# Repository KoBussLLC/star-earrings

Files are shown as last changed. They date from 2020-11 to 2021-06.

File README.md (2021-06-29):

# star-earrings

PCB earrings to show the world that you are there!

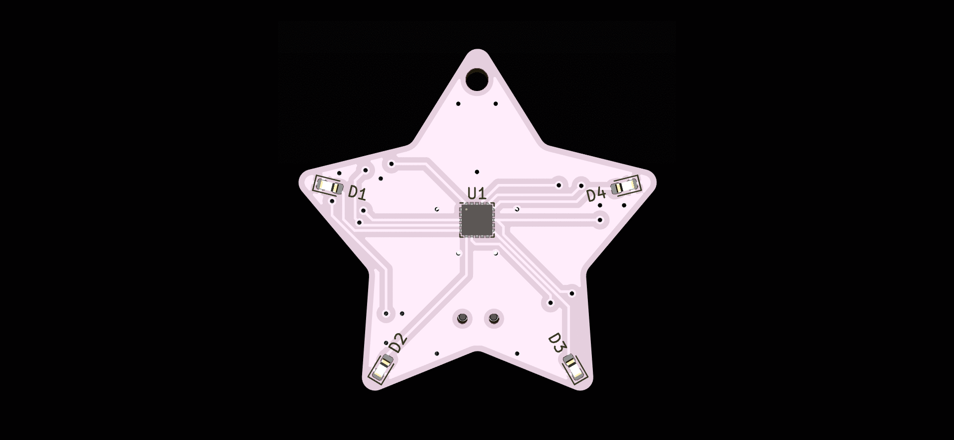
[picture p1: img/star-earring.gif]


## Features

- 4 bright white LEDs
- Mode changing push button
- On/Off Switch
- CR1220 battery life estimated at 570 hours (40mAh/0.07mA)
- Open-source hardware and software allow customizable LED patterns

## Design Considerations

- As light weight as possible -> 0.8mm PCB Thickness
- Balance battery weight/life -> CR1220 Button Cell Battery
- Bright LEDs -> PWM controlled to avoid inline resistor
- Minimal aesthetic -> UFQFPN20 microcontroller footprint
- Power Saving -> STM32L011U6
- No loss of battery while in storage -> Slide switch for on/off
- Mode changing -> Push Button to switch LED patterns
- SMD Manufacturing/Assembly -> 100% SMD Components with dual side panelized assembly

## Firmware

The firmware for the earrings uses the open-source [libopencm3](http://libopencm3.org/) library

- TIM2 used for PWM
- TIM21 used for LED pattern changing interrupt
- EXTI4 Interrupt used for push button
- LPTIM1 used for button debounce

### Generate PWM Sine Waves

Short python3 script to generate breathing pattern array. Modify this script and TIM2 values to customize LED patterns

``` python
import numpy as np
import math

t = np.linspace(0.0, 2.0*math.pi, num=32)
max_ccr = 16.0 
np.set_printoptions(precision=0)
array = np.cos(t)*-1.0*max_ccr + max_ccr + 1.0
array = np.round(array).astype(int)

print(np.array2string(array, formatter={'int':lambda x: str(x)}, separator=', '))
```

## Customer Instructions
 


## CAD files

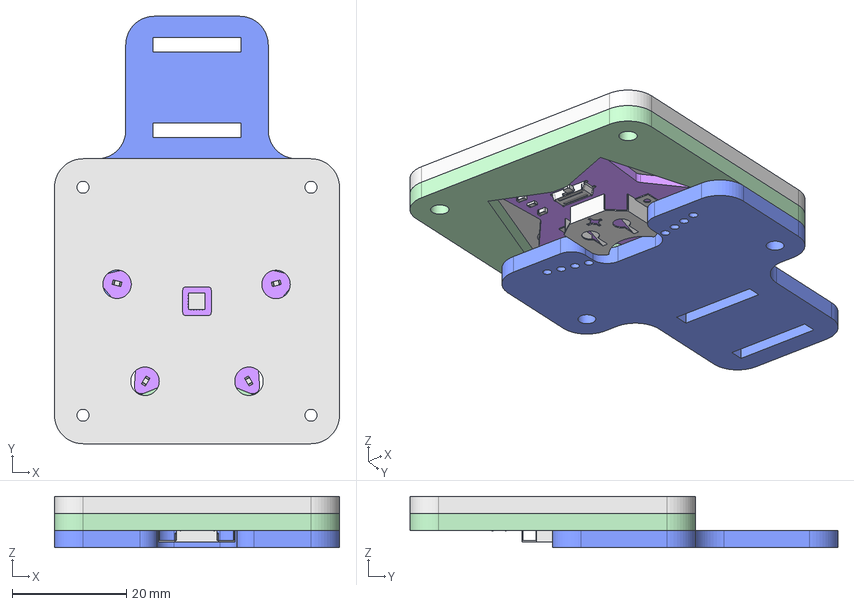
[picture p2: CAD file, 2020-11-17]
cad/programming-fixture.FCStd
50.0 x 75.0 x 9.00 mm
Pcb_46cd
D4_LED_0603_1608Metric_5F4E49DB x 4
U1_ST_UFQFPN_20_3x3mm_P05mm_5F4C40E6
R1_R_0603_1608Metric_5F9A0384
C2_C_0603_1608Metric_5F9CAAD2 x 2
BT1_Keystone_3000_1x12mm_5F4CEA16
SW1_Fusion_sp_5F4F1CB5

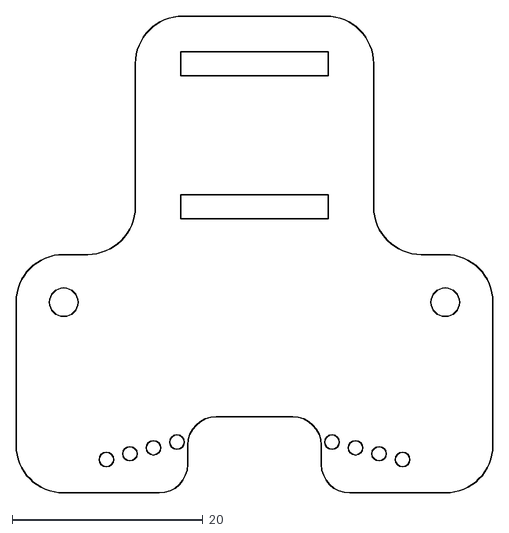
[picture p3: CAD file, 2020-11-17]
cad/programming-fixture-top.dxf
50.0 x 50.0

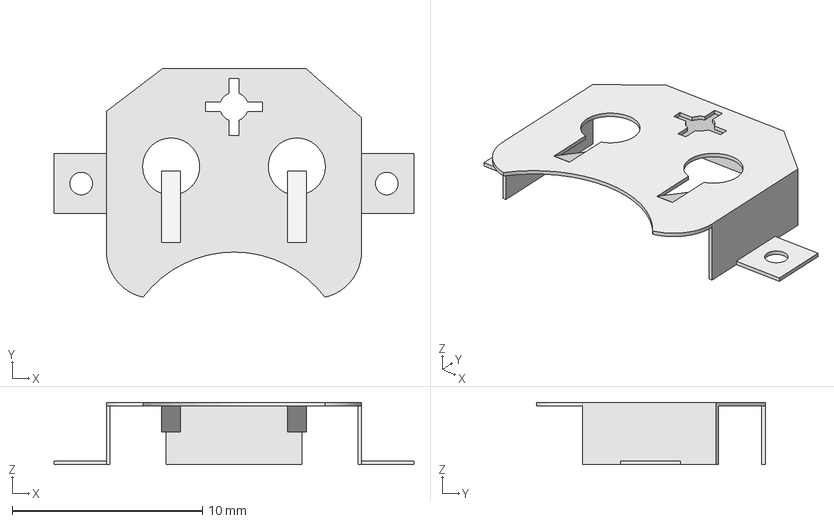
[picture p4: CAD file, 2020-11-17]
cad/BatteryHolderETape.FCStd
18.9 x 12.0 x 3.28 mm

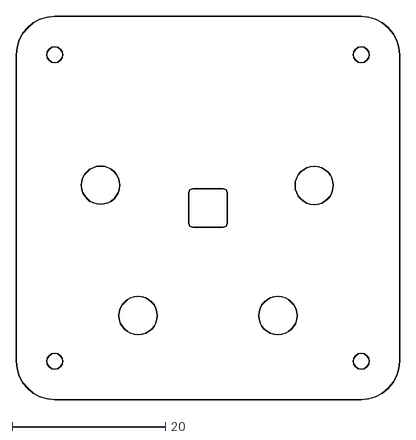
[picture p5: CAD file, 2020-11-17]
cad/programming-fixture-bot.dxf
50.0 x 50.0

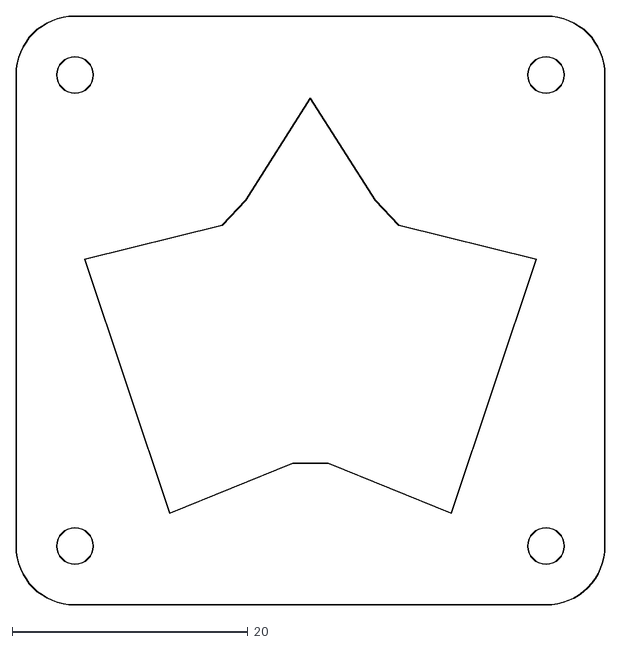
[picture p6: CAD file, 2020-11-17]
cad/programming-fixture-mid.dxf
50.0 x 50.0

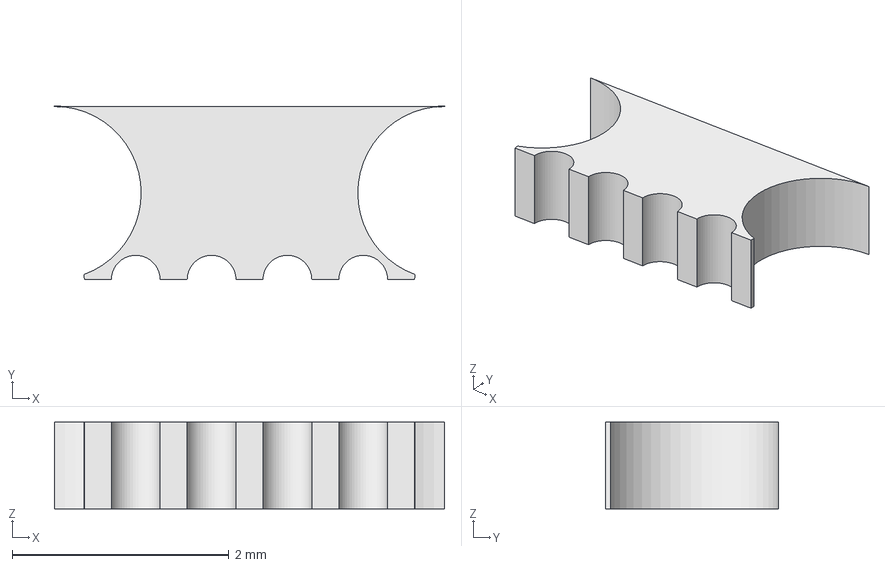
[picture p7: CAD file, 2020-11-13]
cad/mouse-bite.FCStd
3.60 x 1.60 x 0.8 mm

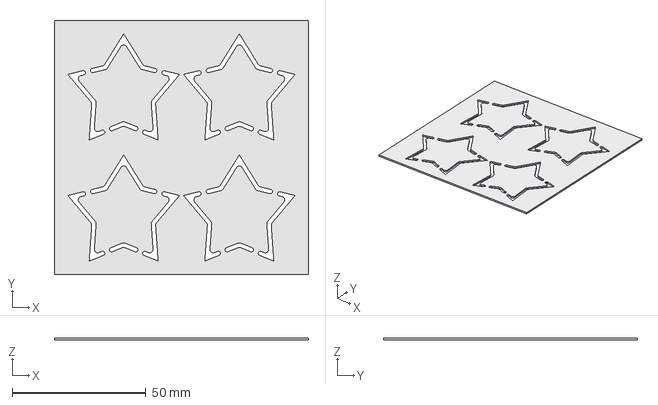
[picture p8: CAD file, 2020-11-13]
cad/starr-earring-panel.FCStd
95.0 x 95.0 x 0.8 mm

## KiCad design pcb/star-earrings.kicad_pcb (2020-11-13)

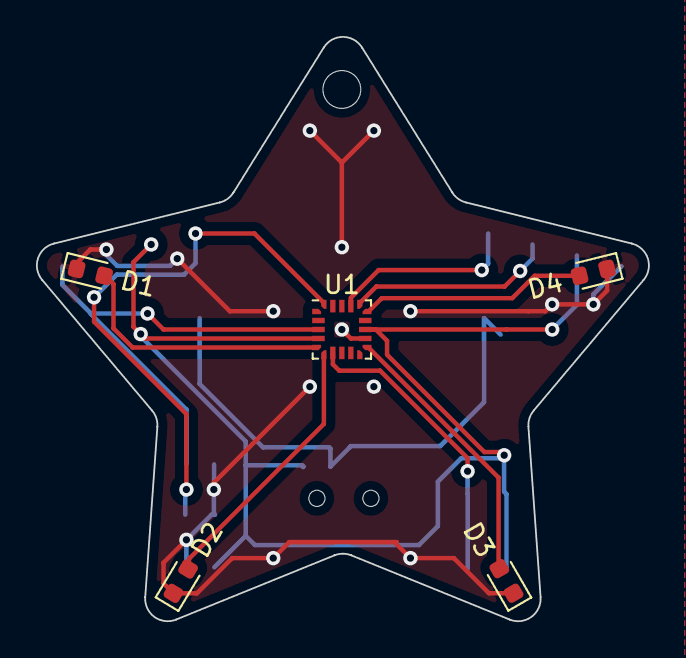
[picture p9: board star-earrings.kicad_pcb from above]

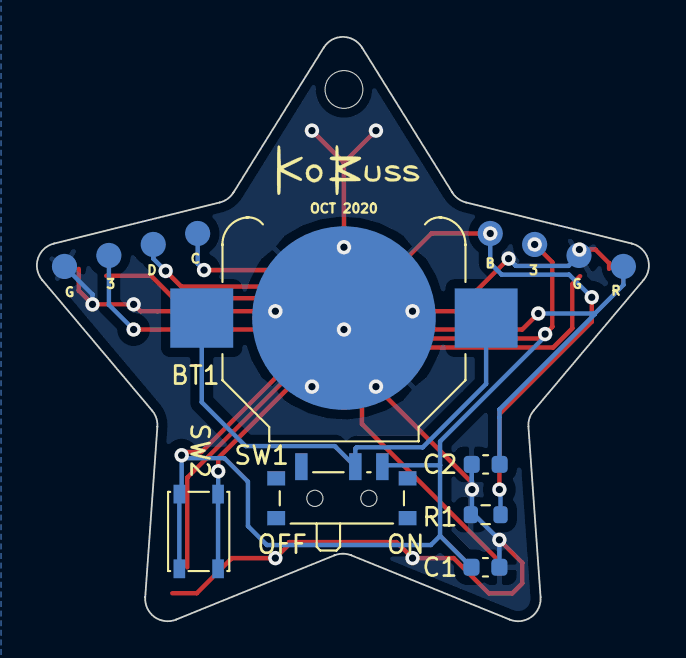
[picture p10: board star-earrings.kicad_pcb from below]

Board: 2 copper layers, 34.0 x 32.5 mm, 15 parts (10 on the bottom side), 12 nets.

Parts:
BT1: Battery_Cell; BatteryHolder_Keystone_3000_1x12mm
C1: 10uF; C_0603_1608Metric
C2: 100nF; C_0603_1608Metric
D1, D2, D3, D4: LED; LED_0603_1608Metric
H1: MountingHole; MountingHole_2.1mm
J1, J2: Conn_01x04_Pad; TestPoint_4Pads_Pitch2.54mm
R1: 10k; R_0603_1608Metric
Ref**: Val**; kobuss_name_s
SW1: SW_SPDT; SW_SPDT_PCM12
SW2: SW_SPST; SW_SPST_PTS810
U1: STM32L011F4Ux; ST_UFQFPN-20_3x3mm_P0.5mm

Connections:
+3V0: C1.1, J1.3, J2.2, SW1.3, SW2.1, U1.4, U1.13
+BATT: BT1.1, SW1.2
GND: BT1.2, C1.2, C2.1, D1.1, D2.1, D3.1, D4.1, J1.4, J2.3, R1.2, U1.12
LED0: D1.2, U1.5
LED1: D2.2, U1.6
LED2: D3.2, U1.11
LED3: D4.2, U1.15
unnamed: C2.2, J2.4, U1.3
unnamed: J2.1, R1.1, U1.20
SWCLK: J1.1, U1.17
SWDIO: J1.2, U1.16
SWITCH: SW2.2, U1.7

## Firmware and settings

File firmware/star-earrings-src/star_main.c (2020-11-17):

#include <libopencm3/stm32/rcc.h>
#include <libopencm3/stm32/gpio.h>
#include <libopencm3/stm32/timer.h>
#include <libopencm3/stm32/lptimer.h>
#include <libopencm3/stm32/exti.h>
#include <libopencm3/stm32/pwr.h>
#include <libopencm3/cm3/nvic.h>

// #define DEBUG

#ifdef DEBUG
#define LED_PIN GPIO15
#define LED_PORT GPIOC
#endif

#define LED0_PORT GPIOA
#define LED0_PIN GPIO0
#define LED1_PORT GPIOA
#define LED1_PIN GPIO1
#define LED2_PORT GPIOB
#define LED2_PIN GPIO1
#define LED3_PORT GPIOA
#define LED3_PIN GPIO10

#define BTN_PORT GPIOA
#define BTN_PIN GPIO4

// TIM21 = 65536/2048 ~= 32 Hz Count increment
#define TIM21_INT_FREQ 32 // Hz
// Button Debounce 0.2ms = x*128/65536Hz
// x = 102 counts
#define DEBOUNCE_CMP_CNT 102

enum LightState
{
    BREATH,
    BLINK,
    ON,
    CHASE,
    ALTERNATE,
    NUM_STATES,
};

volatile uint32_t light_state;
volatile uint32_t tim21_count;
volatile uint32_t debounce = 0;

volatile uint8_t breath_l0[32] = {1, 1, 2, 4, 6, 9, 11, 15, 18, 21, 24, 27, 29, 31, 32, 33, 33, 32, 31, 29, 27, 24, 21, 18, 15, 11, 9, 6, 4, 2, 1, 1};
volatile uint8_t i = 0;
volatile uint8_t j = 0;

void tim21_isr(void)
{
    timer_clear_flag(TIM21, TIM_SR_CC1IF);

    if (i > 31)
    {
        i = 0;
        j++;
    }
    j = j % 4;

    switch (light_state)
    {
    case BREATH:
        switch (j)
        {
        case 0:
            timer_set_oc_value(TIM2, TIM_OC1, breath_l0[i++]);
            timer_set_oc_value(TIM2, TIM_OC2, 1);
            timer_set_oc_value(TIM2, TIM_OC3, 1);
            timer_set_oc_value(TIM2, TIM_OC4, 1);
            break;
        case 1:
            timer_set_oc_value(TIM2, TIM_OC1, 1);
            timer_set_oc_value(TIM2, TIM_OC2, breath_l0[i++]);
            timer_set_oc_value(TIM2, TIM_OC3, 1);
            timer_set_oc_value(TIM2, TIM_OC4, 1);
            break;
        case 2:
            timer_set_oc_value(TIM2, TIM_OC1, 1);
            timer_set_oc_value(TIM2, TIM_OC2, 1);
            timer_set_oc_value(TIM2, TIM_OC3, breath_l0[i++]);
            timer_set_oc_value(TIM2, TIM_OC4, 1);
            break;
        case 3:
            timer_set_oc_value(TIM2, TIM_OC1, 1);
            timer_set_oc_value(TIM2, TIM_OC2, 1);
            timer_set_oc_value(TIM2, TIM_OC3, 1);
            timer_set_oc_value(TIM2, TIM_OC4, breath_l0[i++]);
            break;
        default:
            break;
        }

        break;
    case ON:
        timer_set_oc_value(TIM2, TIM_OC1, 1);
        timer_set_oc_value(TIM2, TIM_OC2, 1);
        timer_set_oc_value(TIM2, TIM_OC3, 1);
        timer_set_oc_value(TIM2, TIM_OC4, 1);
        break;

    case BLINK:
        if (tim21_count < 8)
        {
            timer_set_oc_value(TIM2, TIM_OC1, 1);
            timer_set_oc_value(TIM2, TIM_OC2, 1);
            timer_set_oc_value(TIM2, TIM_OC3, 1);
            timer_set_oc_value(TIM2, TIM_OC4, 1);
        }
        else
        {
            timer_set_oc_value(TIM2, TIM_OC1, 0);
            timer_set_oc_value(TIM2, TIM_OC2, 0);
            timer_set_oc_value(TIM2, TIM_OC3, 0);
            timer_set_oc_value(TIM2, TIM_OC4, 0);
        }
        break;

    case CHASE:
        if (tim21_count < 4)
        {
            timer_set_oc_value(TIM2, TIM_OC1, 1);
            timer_set_oc_value(TIM2, TIM_OC2, 0);
            timer_set_oc_value(TIM2, TIM_OC3, 0);
            timer_set_oc_value(TIM2, TIM_OC4, 0);
        }
        else if (tim21_count >= 4 && tim21_count < 8)
        {
            timer_set_oc_value(TIM2, TIM_OC1, 0);
            timer_set_oc_value(TIM2, TIM_OC2, 1);
            timer_set_oc_value(TIM2, TIM_OC3, 0);
            timer_set_oc_value(TIM2, TIM_OC4, 0);
        }
        else if (tim21_count >= 8 && tim21_count < 12)
        {
            timer_set_oc_value(TIM2, TIM_OC1, 0);
            timer_set_oc_value(TIM2, TIM_OC2, 0);
            timer_set_oc_value(TIM2, TIM_OC3, 1);
            timer_set_oc_value(TIM2, TIM_OC4, 0);
        }
        else
        {
            timer_set_oc_value(TIM2, TIM_OC1, 0);
            timer_set_oc_value(TIM2, TIM_OC2, 0);
            timer_set_oc_value(TIM2, TIM_OC3, 0);
            timer_set_oc_value(TIM2, TIM_OC4, 1);
        }
        break;

    case ALTERNATE:
        if (tim21_count < 8)
        {
            timer_set_oc_value(TIM2, TIM_OC1, 0);
            timer_set_oc_value(TIM2, TIM_OC2, 1);
            timer_set_oc_value(TIM2, TIM_OC3, 0);
            timer_set_oc_value(TIM2, TIM_OC4, 1);
        }
        else
        {
            timer_set_oc_value(TIM2, TIM_OC1, 1);
            timer_set_oc_value(TIM2, TIM_OC2, 0);
            timer_set_oc_value(TIM2, TIM_OC3, 1);
            timer_set_oc_value(TIM2, TIM_OC4, 0);
        }
        break;

    default:
        break;
    }

    tim21_count = (tim21_count + 1) % 16;
}

void exti4_15_isr(void)
{
    exti_reset_request(EXTI4);
    if (debounce == 0 && gpio_get(BTN_PORT, BTN_PIN) != 0)
    {
        debounce = 1;
        lptimer_enable(LPTIM1);
        lptimer_set_counter(LPTIM1, 0);
        lptimer_set_compare(LPTIM1, DEBOUNCE_CMP_CNT);   //
        lptimer_start_counter(LPTIM1, LPTIM_CR_SNGSTRT); // Start timer
#ifdef DEBUG
        gpio_set(LED_PORT, LED_PIN);
#endif
        light_state = (light_state + 1) % NUM_STATES;
    }
}

void lptim1_isr(void)
{
    lptimer_clear_flag(LPTIM1, LPTIM_ICR_CMPMCF | LPTIM_ICR_ARRMCF);
    lptimer_disable(LPTIM1);
    debounce = 0;
#ifdef DEBUG
    gpio_clear(LED_PORT, LED_PIN);
#endif
}

int main(void)
{
    // Set clock to internal clock at lowest speed
    rcc_set_msi_range(RCC_ICSCR_MSIRANGE_65KHZ);

    rcc_set_sysclk_source(RCC_MSI);

    rcc_set_hpre(RCC_CFGR_HPRE_NODIV);

    rcc_set_ppre1(RCC_CFGR_PPRE1_NODIV);
    rcc_set_ppre2(RCC_CFGR_PPRE2_NODIV);

    // Initialize peripherals access to clock
    rcc_periph_clock_enable(RCC_GPIOA);
    rcc_periph_clock_enable(RCC_GPIOB);
#ifdef DEBUG
    rcc_periph_clock_enable(RCC_GPIOC);
#endif
    rcc_periph_clock_enable(RCC_TIM2);
    rcc_periph_clock_enable(RCC_TIM21);
    rcc_periph_clock_enable(RCC_LPTIM1);

    // Setup GPIO
#ifdef DEBUG
    gpio_mode_setup(LED_PORT, GPIO_MODE_OUTPUT, GPIO_PUPD_NONE, LED_PIN);
#endif

    gpio_mode_setup(LED0_PORT, GPIO_MODE_AF, GPIO_PUPD_NONE, LED0_PIN);
    gpio_mode_setup(LED1_PORT, GPIO_MODE_AF, GPIO_PUPD_NONE, LED1_PIN);
    gpio_mode_setup(LED2_PORT, GPIO_MODE_AF, GPIO_PUPD_NONE, LED2_PIN);
    gpio_mode_setup(LED3_PORT, GPIO_MODE_AF, GPIO_PUPD_NONE, LED3_PIN);

    gpio_set_af(LED0_PORT, GPIO_AF2, LED0_PIN);
    gpio_set_af(LED1_PORT, GPIO_AF2, LED1_PIN);
    gpio_set_af(LED2_PORT, GPIO_AF5, LED2_PIN);
    gpio_set_af(LED3_PORT, GPIO_AF5, LED3_PIN);

    gpio_set_output_options(LED0_PORT, GPIO_OTYPE_PP, GPIO_OSPEED_LOW, LED0_PIN);
    gpio_set_output_options(LED1_PORT, GPIO_OTYPE_PP, GPIO_OSPEED_LOW, LED1_PIN);
    gpio_set_output_options(LED2_PORT, GPIO_OTYPE_PP, GPIO_OSPEED_LOW, LED2_PIN);
    gpio_set_output_options(LED3_PORT, GPIO_OTYPE_PP, GPIO_OSPEED_LOW, LED3_PIN);

    // TIM2 Setup for PWM on all channels
    timer_set_mode(TIM2, TIM_CR1_CKD_CK_INT, TIM_CR1_CMS_EDGE, TIM_CR1_DIR_UP);

    timer_set_prescaler(TIM2, 0);
    timer_continuous_mode(TIM2);
    timer_set_period(TIM2, 1024);

    timer_disable_oc_output(TIM2, TIM_OC1);
    timer_disable_oc_output(TIM2, TIM_OC2);
    timer_disable_oc_output(TIM2, TIM_OC3);
    timer_disable_oc_output(TIM2, TIM_OC4);
    timer_disable_oc_clear(TIM2, TIM_OC1);
    timer_disable_oc_clear(TIM2, TIM_OC2);
    timer_disable_oc_clear(TIM2, TIM_OC3);
    timer_disable_oc_clear(TIM2, TIM_OC4);
    timer_enable_oc_preload(TIM2, TIM_OC1);
    timer_enable_oc_preload(TIM2, TIM_OC2);
    timer_enable_oc_preload(TIM2, TIM_OC3);
    timer_enable_oc_preload(TIM2, TIM_OC4);
    timer_set_oc_slow_mode(TIM2, TIM_OC1);
    timer_set_oc_slow_mode(TIM2, TIM_OC2);
    timer_set_oc_slow_mode(TIM2, TIM_OC3);
    timer_set_oc_slow_mode(TIM2, TIM_OC4);
    timer_set_oc_mode(TIM2, TIM_OC1, TIM_OCM_PWM1);
    timer_set_oc_mode(TIM2, TIM_OC2, TIM_OCM_PWM1);
    timer_set_oc_mode(TIM2, TIM_OC3, TIM_OCM_PWM1);
    timer_set_oc_mode(TIM2, TIM_OC4, TIM_OCM_PWM1);
    timer_set_oc_value(TIM2, TIM_OC1, 1);
    timer_set_oc_value(TIM2, TIM_OC2, 1);
    timer_set_oc_value(TIM2, TIM_OC3, 1);
    timer_set_oc_value(TIM2, TIM_OC4, 1);
    timer_enable_oc_output(TIM2, TIM_OC1);
    timer_enable_oc_output(TIM2, TIM_OC2);
    timer_enable_oc_output(TIM2, TIM_OC3);
    timer_enable_oc_output(TIM2, TIM_OC4);

    timer_enable_counter(TIM2);

    // TIM21 Setup for IRQ to update TIM2 CCR values
    nvic_enable_irq(NVIC_TIM21_IRQ);
    rcc_periph_reset_pulse(RST_TIM21);
    timer_set_mode(TIM21, TIM_CR1_CKD_CK_INT, TIM_CR1_CMS_EDGE, TIM_CR1_DIR_UP);
    timer_disable_preload(TIM21);
    timer_continuous_mode(TIM21);
    // TIM21 frequency = 65536/2048 = 32Hz
    timer_set_prescaler(TIM21, 2047);
    timer_set_period(TIM21, 32 / TIM21_INT_FREQ);
    timer_enable_counter(TIM21);
    timer_enable_irq(TIM21, TIM_DIER_CC1IE);

    // EXTI setup for push button to toggle modes
    gpio_mode_setup(BTN_PORT, GPIO_MODE_INPUT, GPIO_PUPD_PULLDOWN, BTN_PIN);
    exti_select_source(EXTI4, BTN_PORT);
    exti_set_trigger(EXTI4, EXTI_TRIGGER_RISING);
    exti_enable_request(EXTI4);
    nvic_enable_irq(NVIC_EXTI4_15_IRQ);

    // Setup LPTIM1 for button debounce
    nvic_enable_irq(NVIC_LPTIM1_IRQ);
    rcc_periph_reset_pulse(RST_LPTIM1);
    lptimer_set_internal_clock_source(LPTIM1);
    lptimer_disable_preload(LPTIM1);
    lptimer_set_prescaler(LPTIM1, LPTIM_CFGR_PRESC_128);
    // Enable LPTIM1 in order to set period, then disable
    lptimer_enable(LPTIM1);
    lptimer_set_counter(LPTIM1, 0);
    lptimer_set_period(LPTIM1, 0xFFFF); // Using Compare, so set to max period
    lptimer_disable(LPTIM1);
    lptimer_enable_irq(LPTIM1, LPTIM_IER_CMPMIE);

    while (1)
    {
        // Attempt to save power, although most power saving
        // is coming from the low clock speed
        pwr_set_stop_mode();
    }

    return 0;
}

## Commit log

2020-11-07 Button debounce implemented
2020-11-07 LED Breathing Pattern Default
2020-11-13 Hardware V0
    [mouse-bite.FCStd, programming-fixture.FCStd, star-earrings-panel.kicad_pcb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]
2020-11-17 V1 firmware update with fixture CAD
    [BatteryHolderETape.FCStd, programming-fixture-bot.dxf, programming-fixture-mid.dxf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]
2020-12-07 Added battery insertion step
2020-12-07 fixed battery plus sign
